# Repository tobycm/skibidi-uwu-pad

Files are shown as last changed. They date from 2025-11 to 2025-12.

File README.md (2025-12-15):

# skibidi-uwu-pad

me when i osu

## features:

- 3 hall effects switches
- 2 cherry mx switches
- 1 rotary encoder with push function
- rgb underglow
- hot swappable keycaps
- customizable firmware via zmk
- usb/bluetooth connectivity
- 3.7V li-ion battery
- smart battery power saving mode

## renders:

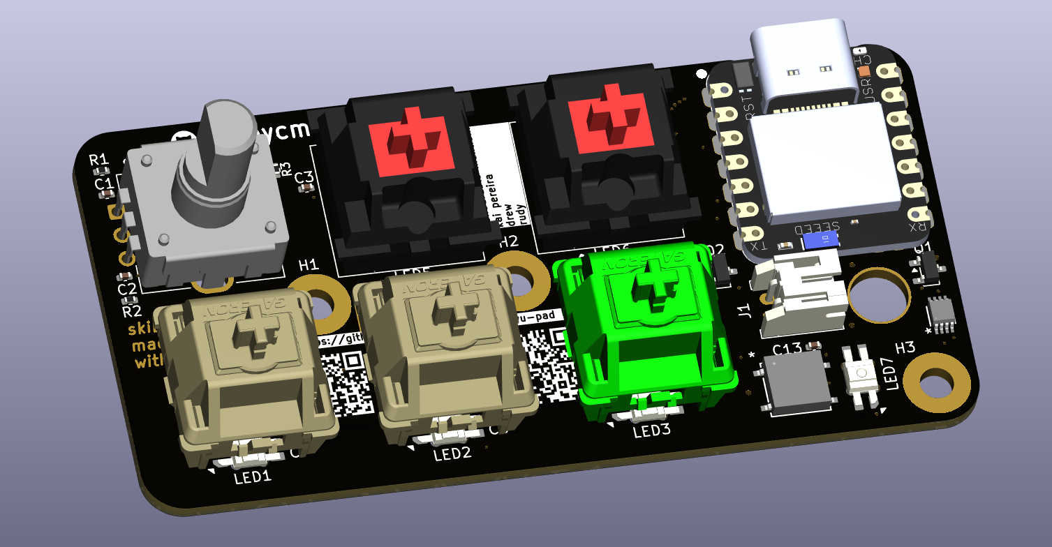
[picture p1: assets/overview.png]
overview


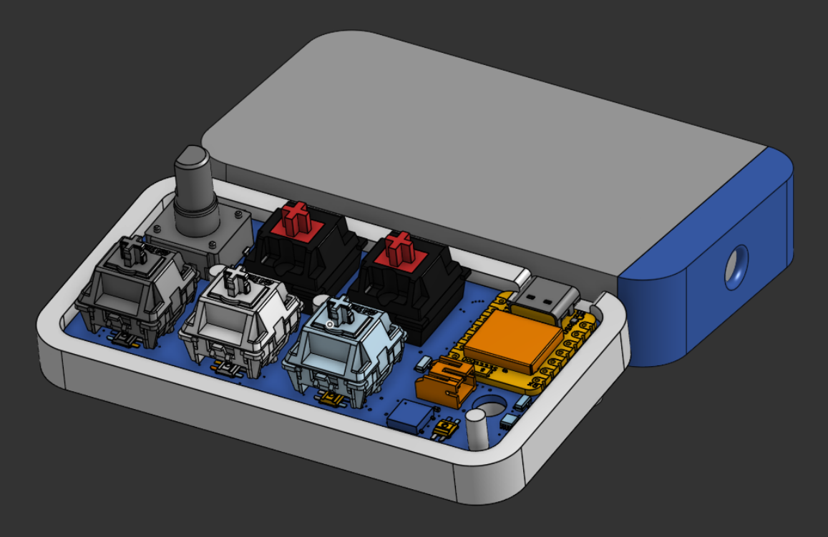
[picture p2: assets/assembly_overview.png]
assembly overview


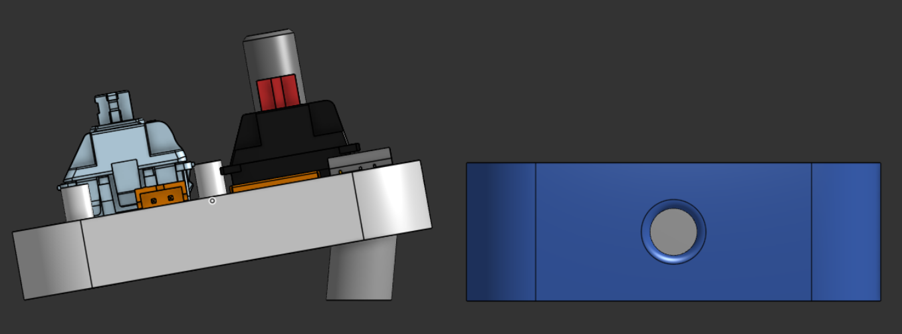
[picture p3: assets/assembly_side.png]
assembly side


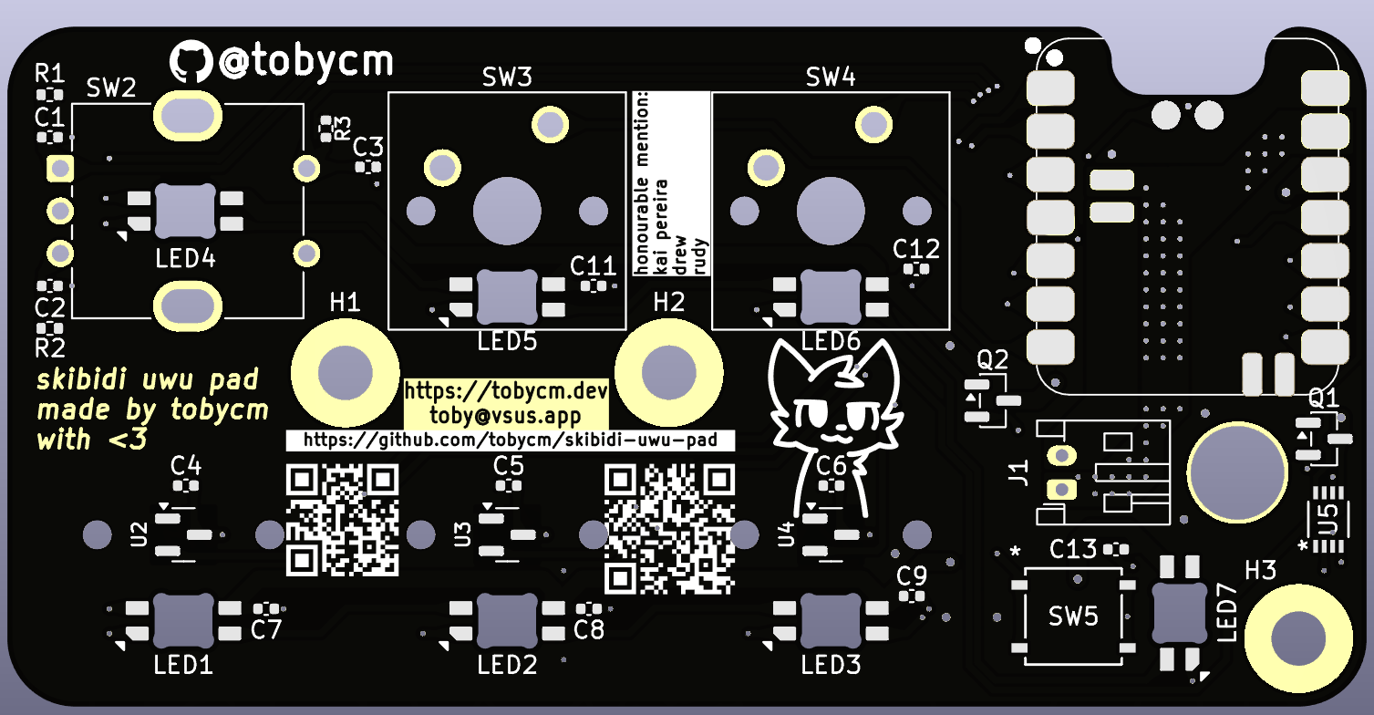
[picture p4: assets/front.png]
front


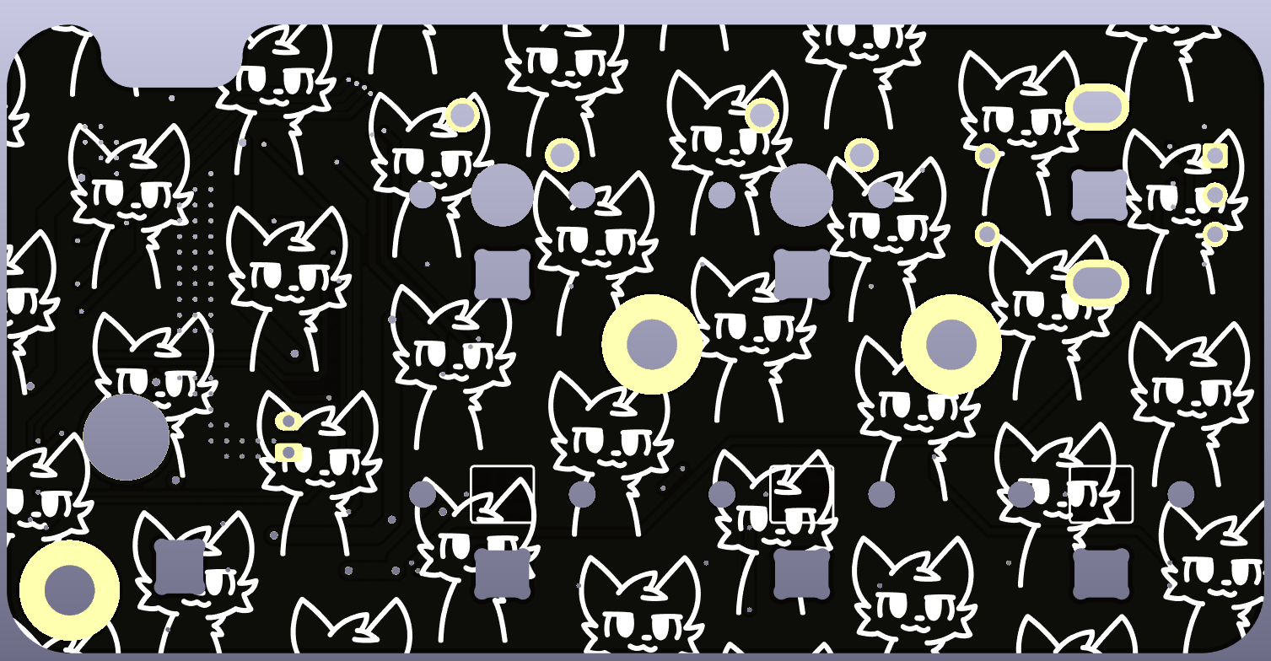
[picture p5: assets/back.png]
back


## schematic

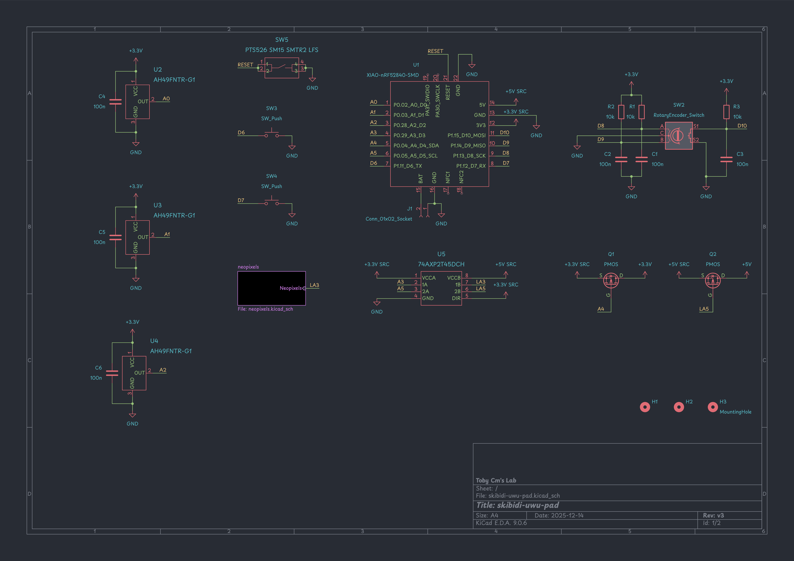
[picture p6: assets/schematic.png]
schematic


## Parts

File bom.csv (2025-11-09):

Qty | Value | CAD | USD | Link
12 | 100nF |  |  |  | USD/CAD rate | 1.42
1 | S2B-PH-K-S
5 | MX_SK6812MINI-E
2 | SK6812MINI-E | $6.79 | $4.78 | https://www.aliexpress.com/item/1005007696173500.html
3 | 10kohm
1 | PEC12R-2217F-S0024
2 | MX1A-E1NN
1 | GSPTS004901
1 | XIAO NRF52840
3 | 31-AH49FNTR-G1CT-ND
 | Digikey Total | $52.26 | $36.80 | https://www.digikey.ca/short/tm8cttnv
 | 3.7V Lipo Battery | $13.89 | $9.78 | https://www.aliexpress.com/item/1005008218024646.html
 | GATERON Magnetic Jade Pro Switch | $13.58 | $9.56 | https://www.aliexpress.com/item/1005008169504340.html
 | Pink keycaps | $4.79 | $3.37 | https://www.aliexpress.com/item/1005009531843221.html
 | Transparent keycaps | $6.39 | $4.50 | https://www.aliexpress.com/item/1005002976015114.html
 | PCB |  | $4.60 | https://jlcpcb.com/
 | Total | $97.70 | $68.80

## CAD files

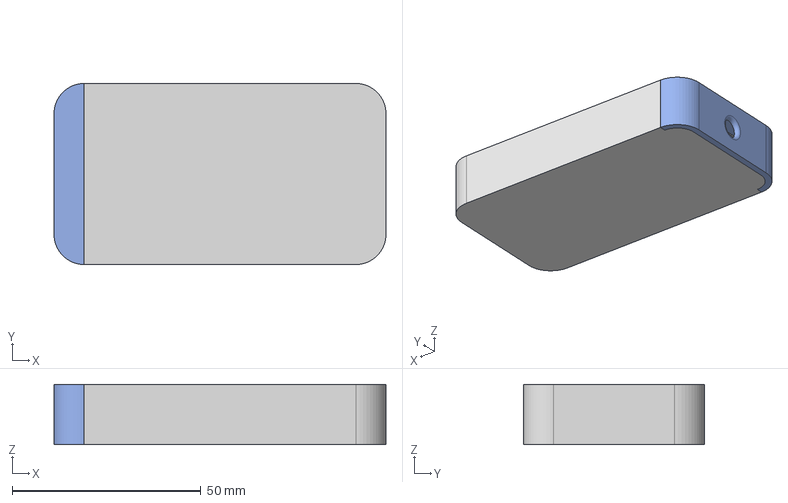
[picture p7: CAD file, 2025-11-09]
cad/battery case.step
88.0 x 48.0 x 16.0 mm

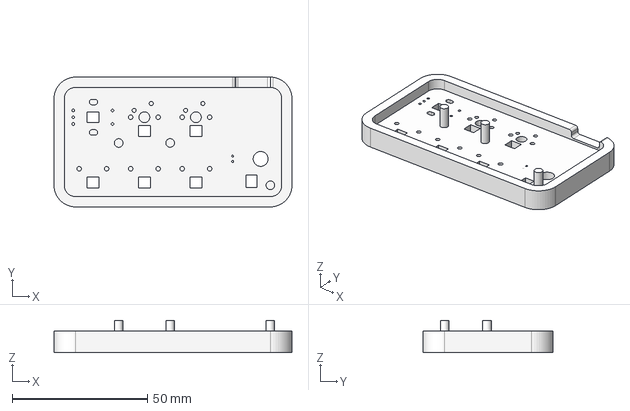
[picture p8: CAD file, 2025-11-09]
cad/holder.step
88.0 x 48.0 x 12.0 mm

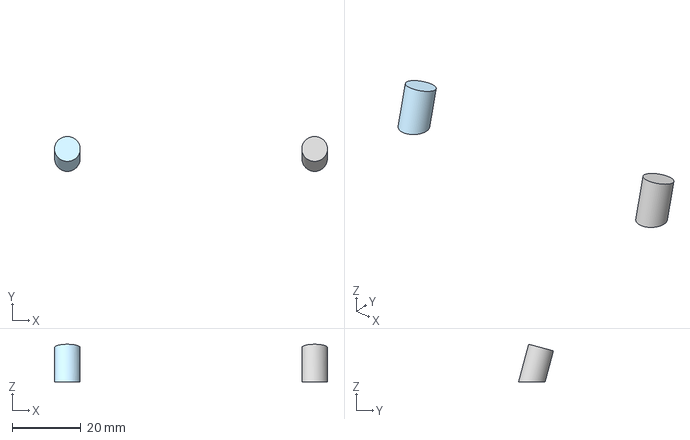
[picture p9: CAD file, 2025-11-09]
cad/feet.step
79.5 x 10.2 x 10.9 mm

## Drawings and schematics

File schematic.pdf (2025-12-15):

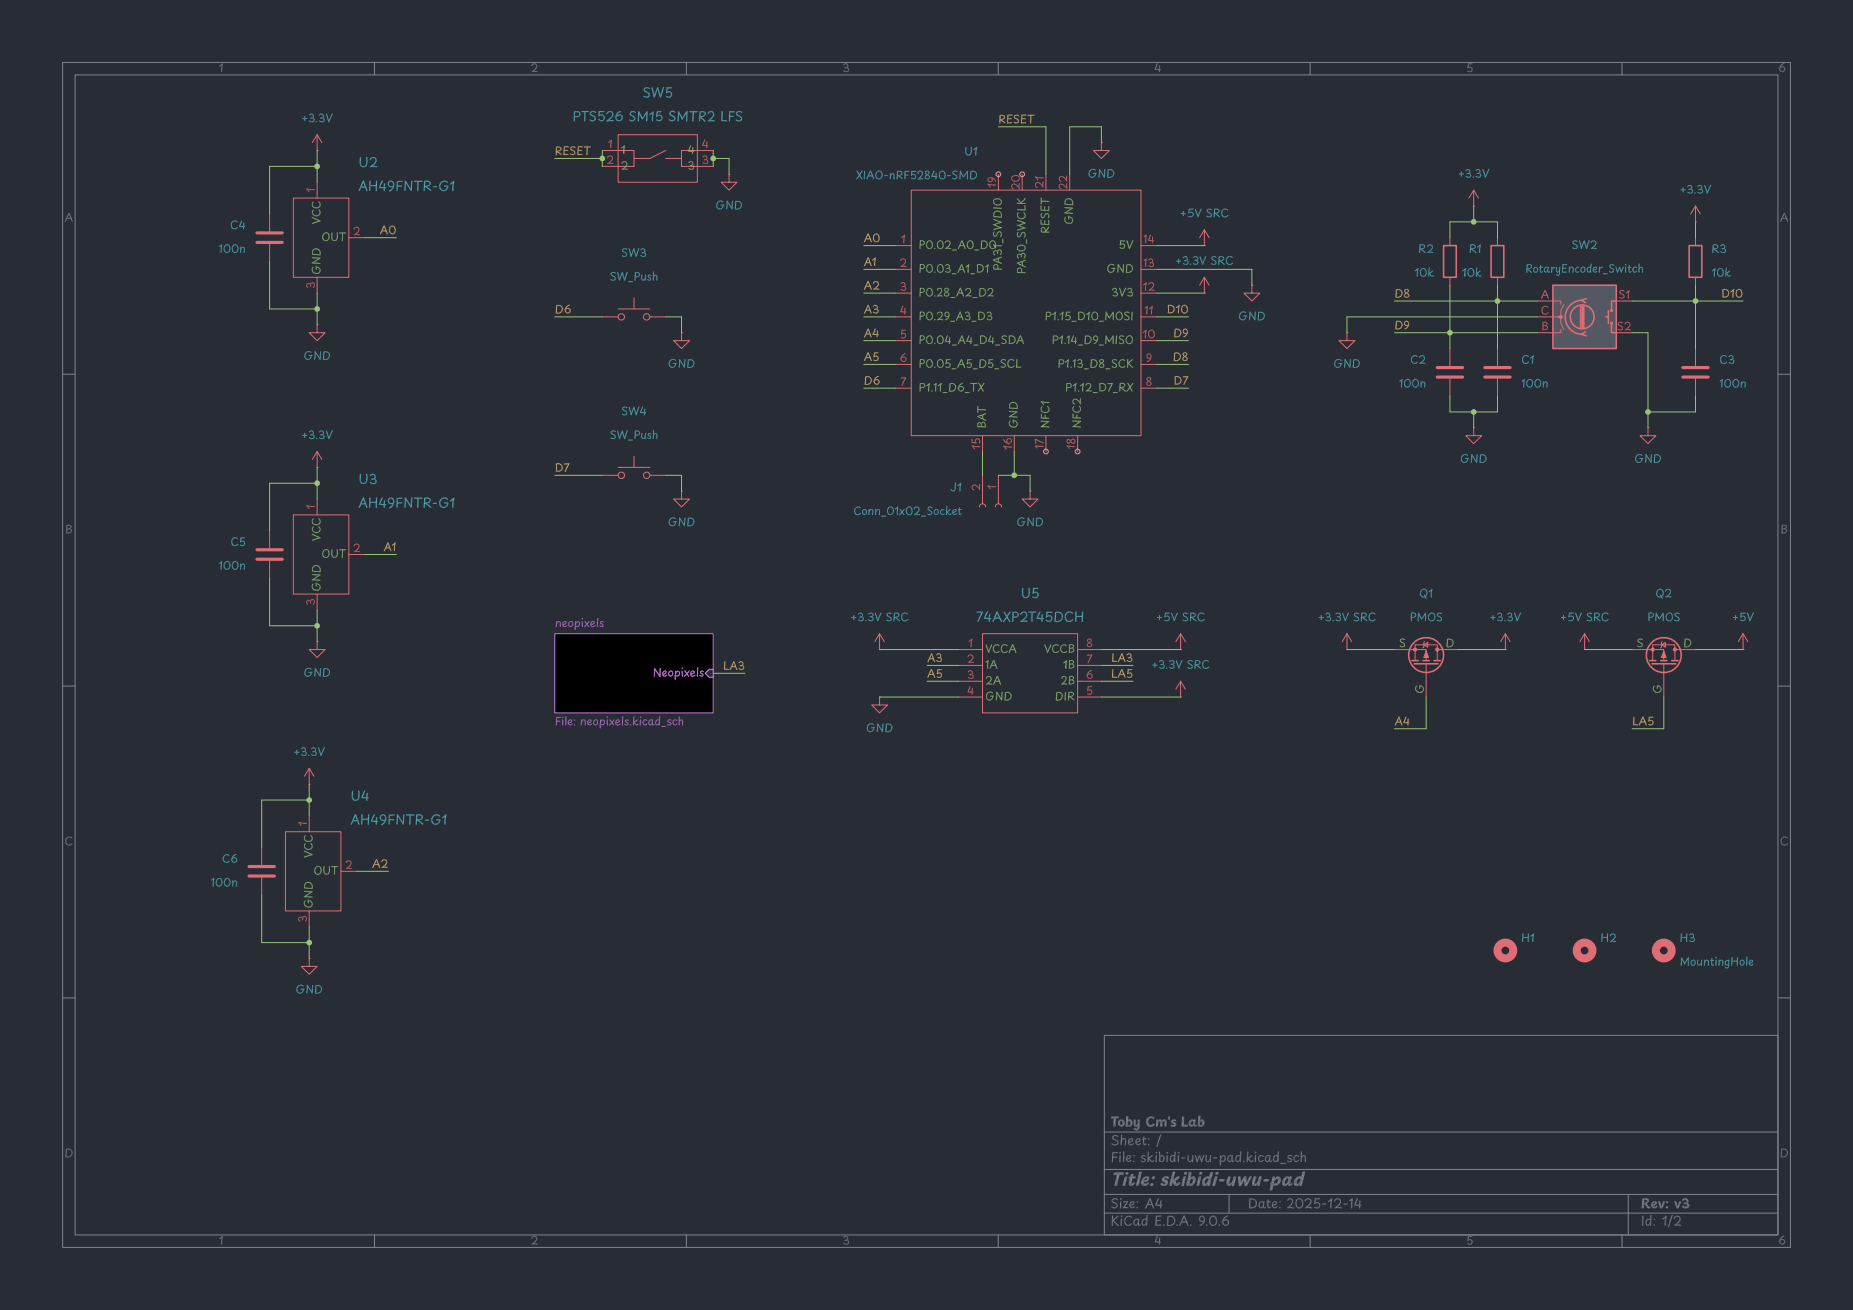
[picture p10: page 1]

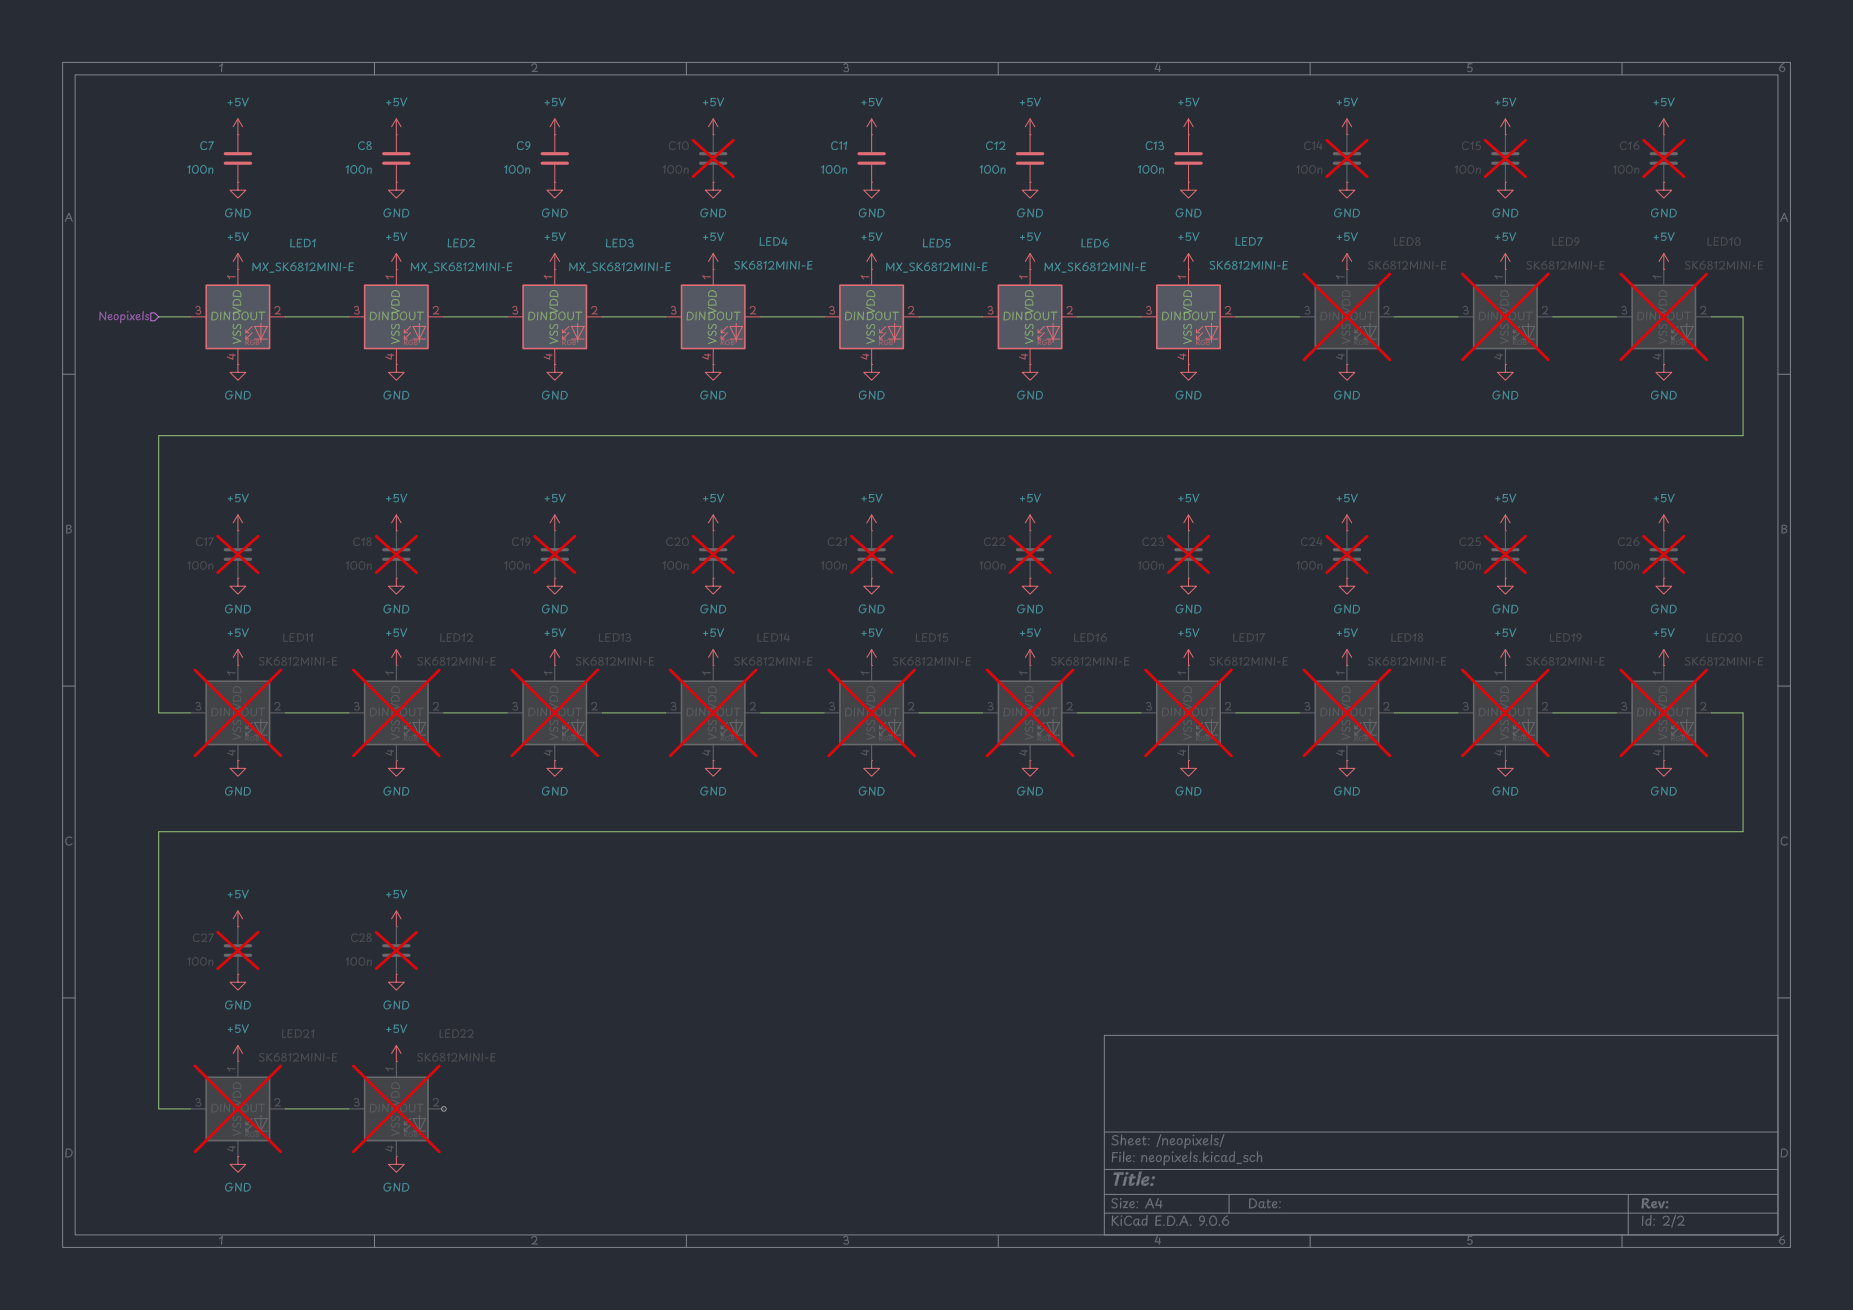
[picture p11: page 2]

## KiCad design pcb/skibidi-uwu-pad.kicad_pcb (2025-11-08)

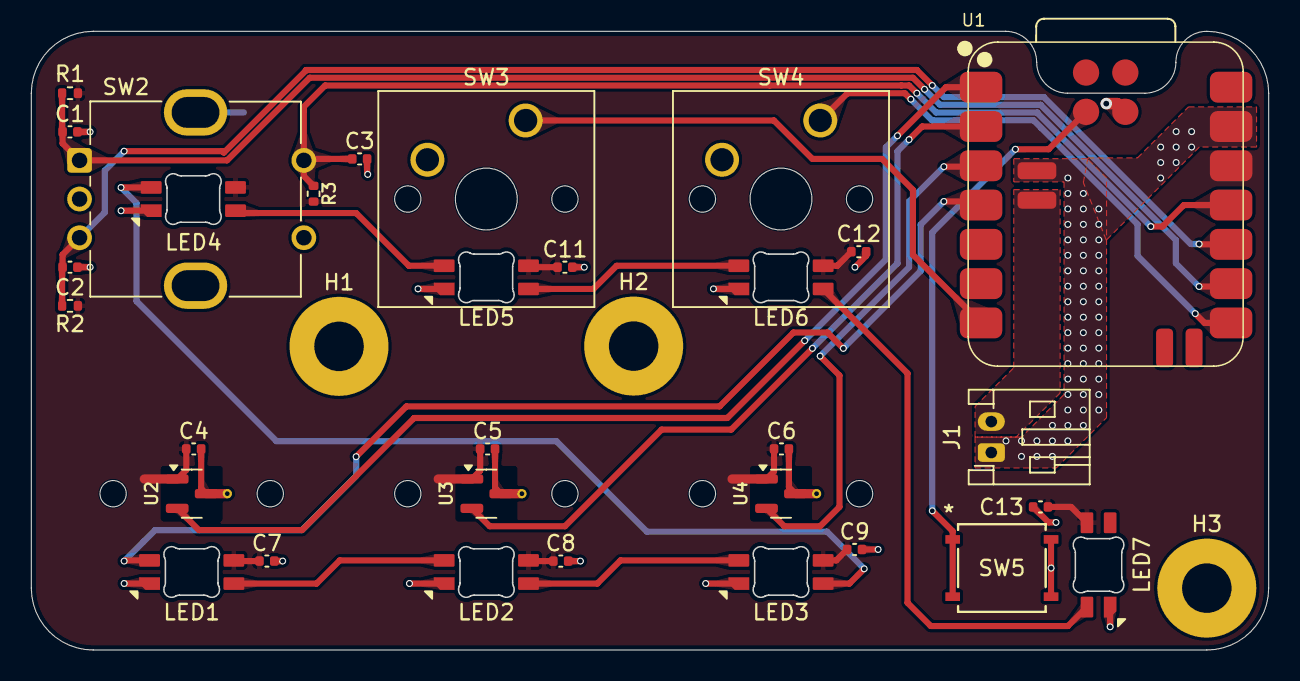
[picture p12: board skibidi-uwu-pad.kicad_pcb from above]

Board: 2 copper layers, 80.0 x 40.0 mm, 34 parts (0 on the bottom side), 19 nets.

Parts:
C1, C2, C3, C4, C5, C6, C7, C8, C9, C11, C12, C13: 100n; C_0402_1005Metric
H1, H2, H3: MountingHole; MountingHole_3.2mm_M3_Pad
J1: Conn_01x02_Socket; JST_PH_S2B-PH-K_1x02_P2.00mm_Horizontal
LED1, LED2, LED3, LED5, LED6: MX_SK6812MINI-E; LED_MX_6028R
LED4, LED7: SK6812MINI-E; LED_6028R
R1, R2, R3: 10k; R_0402_1005Metric
SW2: RotaryEncoder_Switch; RotaryEncoder_Bourns_Vertical_PEC12R-3x17F-Sxxxx
SW3, SW4: SW_Push; SW_Cherry_MX_1.00u_PCB
SW5: PTS526 SM15 SMTR2 LFS; SON4_PTS526 SM15 SMTR2 LFS_CNK
U1: XIAO-nRF52840-SMD
U2, U3, U4: AH49FNTR-G1; SW_MX_HE_0deg_1u

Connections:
+3.3V: C4.1, C5.1, C6.1, C7.1, C8.1, C9.1, C11.1, C12.1, C13.1, LED1.1 (VDD), LED2.1 (VDD), LED3.1 (VDD), LED4.1 (VDD), LED5.1 (VDD), LED6.1 (VDD), LED7.1 (VDD), R1.1, R2.1, R3.1, U1.12 (3V3), U2.1 (VCC), U3.1 (VCC), U4.1 (VCC)
/A0: U1.1 (P0.02_A0_D0), U2.2 (OUT)
/A1: U1.2 (P0.03_A1_D1), U3.2 (OUT)
/A2: U1.3 (P0.28_A2_D2), U4.2 (OUT)
/A3: LED1.3 (DIN), U1.4 (P0.29_A3_D3)
/D6: SW3.1, U1.7 (P1.11_D6_TX)
/D7: SW4.1, U1.8 (P1.12_D7_RX)
/D8: C1.1, R1.2, SW2.A, U1.9 (P1.13_D8_SCK)
/D9: C2.1, R2.2, SW2.B, U1.10 (P1.14_D9_MISO)
/D10: C3.1, R3.2, SW2.S1, U1.11 (P1.15_D10_MOSI)
/RESET: SW5.1, SW5.2, U1.21 (RESET)
GND: C1.2, C2.2, C3.2, C4.2, C5.2, C6.2, C7.2, C8.2, C9.2, C11.2, C12.2, C13.2, J1.1, LED1.4 (VSS), LED2.4 (VSS), LED3.4 (VSS), LED4.4 (VSS), LED5.4 (VSS), LED6.4 (VSS), LED7.4 (VSS), SW2.C, SW2.S2, SW3.2, SW4.2, SW5.3, SW5.4, U1.13 (GND), U1.16 (GND), U1.22 (GND), U2.3 (GND), U3.3 (GND), U4.3 (GND)
unnamed: J1.2, U1.15 (BAT)
unnamed: LED1.2 (DOUT), LED2.3 (DIN)
unnamed: LED2.2 (DOUT), LED3.3 (DIN)
unnamed: LED3.2 (DOUT), LED4.3 (DIN)
unnamed: LED4.2 (DOUT), LED5.3 (DIN)
unnamed: LED5.2 (DOUT), LED6.3 (DIN)
unnamed: LED6.2 (DOUT), LED7.3 (DIN)

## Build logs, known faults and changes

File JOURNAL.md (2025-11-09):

<!--
  ===================    !!READ THIS NOTICE!!   ====================
  DO NOT edit this file manually. Your changes WILL BE OVERWRITTEN!
  This journal is auto generated and updated by Hack Club Blueprint.
  To edit this file, please edit your journal entries on Blueprint.
  ==================================================================
-->

## 11/8/2025 12:20 AM - shopping  

went shopping on lcsc, and aliexpress

lcsc smh too expensive with the shipping and miscellanous other fees, also doesnt have the seeed xiaos on there so i buy stuff from digikey instead...



## 11/8/2025 12:21 AM - drawing schematic  

schematic drew!!!!

2 sheets, one for main logic, other one for neopixels. its pretty simple imo, hopefully the pcb will be as easy to route asdnskdfhksjdf



## 11/8/2025 2:04 AM - pcb routing is done  

pcb routing is done, very neat, very organized. next is to do cad, i have some transparent filament so hopefully that works out hehe asdasddfugdfereaas



## 11/8/2025 2:50 AM - wrote Readme.md and init firmware  

tidied up the readme and tried out zmk config. trying to learn how zmk works. https://zmk.dev/docs/customization https://zmk.dev/docs/customization ..



## 11/9/2025 1 AM - added pcb art and power saving mechanism  

added lots of pcb art, infos, etc. added power saving mechanism, to cut power to neopixels and sensors when not actively in use. saves battery like 104060 li ion



## 11/9/2025 1 PM - cad the case  

its just so peak....

Screenshot from 2025-11-09 12-45-15

so so peak.......

Screenshot from 2025-11-09 12-47-24

tooooo peakkkk...........

Screenshot from 2025-11-09 13-01-57
........................................................................................

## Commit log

2025-11-08 PoC done!
    [bom.csv, bom.ods, neopixels.kicad_sch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]
2025-11-08 forgor to add pcb :skull:
    [bom.csv, bom.ods]
2025-11-09 add smart power saving circuit + update readme
    [bom.csv, bom.ods, neopixels.kicad_sch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]
2025-11-09 make a fancy case whoaaaaa
    [battery case.step, feet.step, holder.step]
2025-11-09 update bom
    [bom.csv, bom.ods]
2025-12-15 add schematic
    [skibidi-uwu-pad.kicad_sch]
